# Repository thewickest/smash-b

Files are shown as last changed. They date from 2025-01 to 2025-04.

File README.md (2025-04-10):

# Smashboard
Ortholinear bluetooth split keyboard.

Just another split keyboard. Developed with KiKad7.0 and Fusion360.

ZMK configuration in [Smashboard-config](https://github.com/thewickest/smashboard-config)





# Features
- Powered by nice!nano microcontroller
- Compatible with nice!view OLED screen
- Hotswap for MX style Switches
- Different types of cases
- ZMK
- VIA Support
- Bluetooth

# Assembly
Parts needed. I will be linking the parts that I used. Feel free to use other parts, specially for the switches and the hotswap sockets. You can also change the remaining parts but you will have to modify the PCB most probably.
- 2x nice!nano
- 2x nice!view (optional)
- 44x MX Style switches
- 44x Hotswap sockets
- 48x Millmax sockets
- 10x millmax headers sockets
- 2x JST Battery connector (optional)
- 2x Power off/on switch
- 2x Reset button

# Roadmap
- [ ] Hotswap for low profile switches
- [x] Shell case

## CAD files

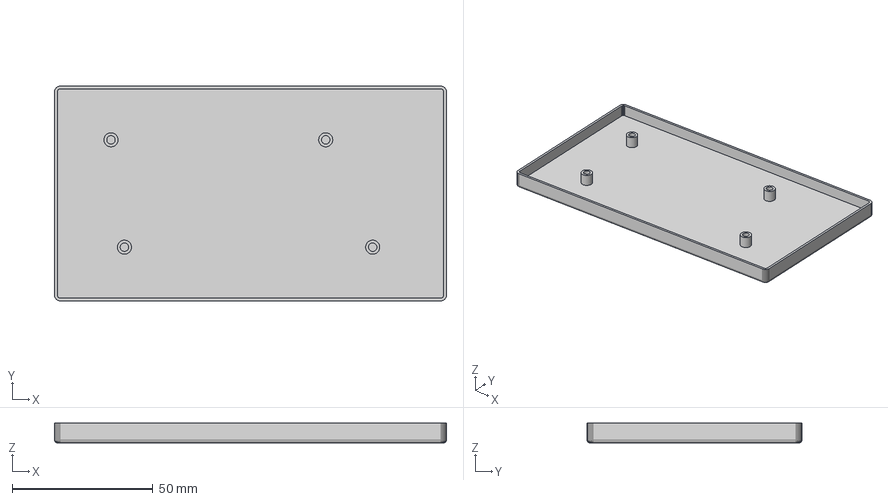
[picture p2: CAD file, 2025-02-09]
case/notoppings/notoppings.step
139.1 x 76.2 x 7.00 mm

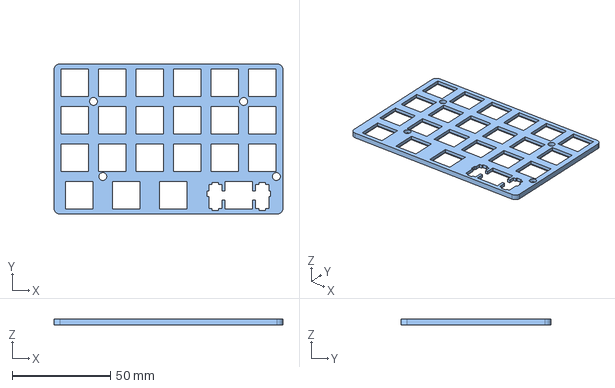
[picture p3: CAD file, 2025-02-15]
case/plate.step
116.3 x 76.2 x 3.00 mm

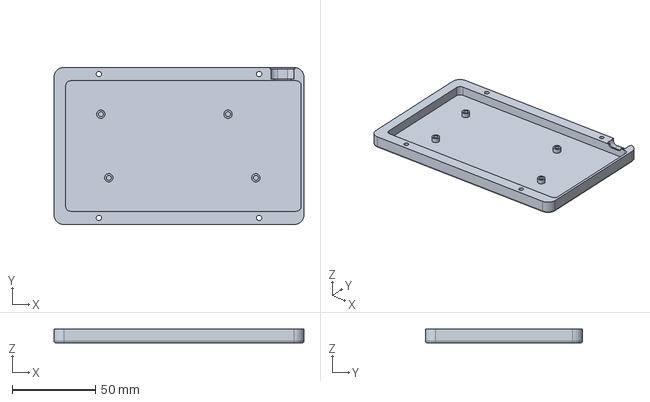
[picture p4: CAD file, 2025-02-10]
case/theclassic/theclassic-bottom.step
149.8 x 94.2 x 8.19 mm

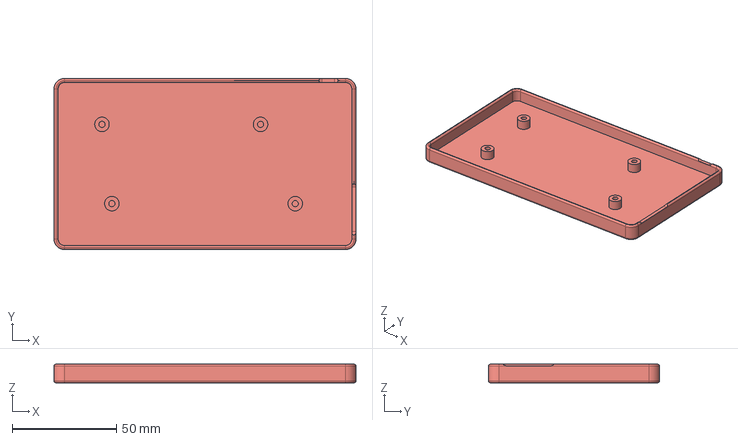
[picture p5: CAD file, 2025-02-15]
case/twopatties/twopatties.step
145.1 x 82.2 x 9.00 mm

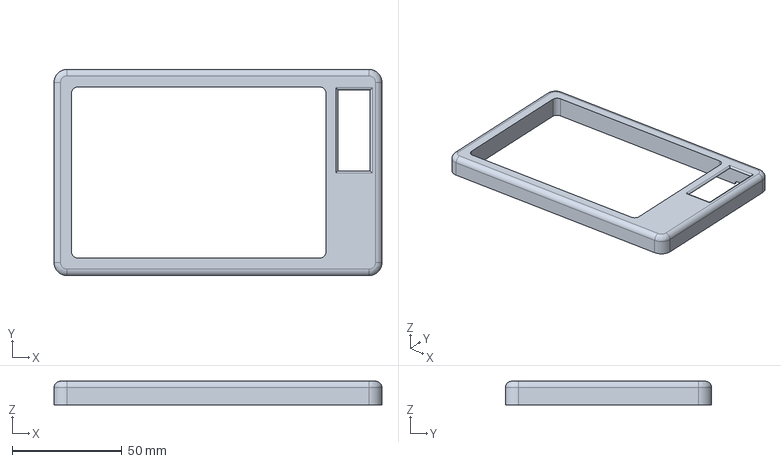
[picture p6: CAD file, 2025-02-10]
case/theclassic/theclassic-top.step
149.8 x 94.2 x 10.8 mm

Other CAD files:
case/notoppings/notoppings.obj
case/theclassic/theclassic-bottom.obj
case/theclassic/theclassic-top.obj

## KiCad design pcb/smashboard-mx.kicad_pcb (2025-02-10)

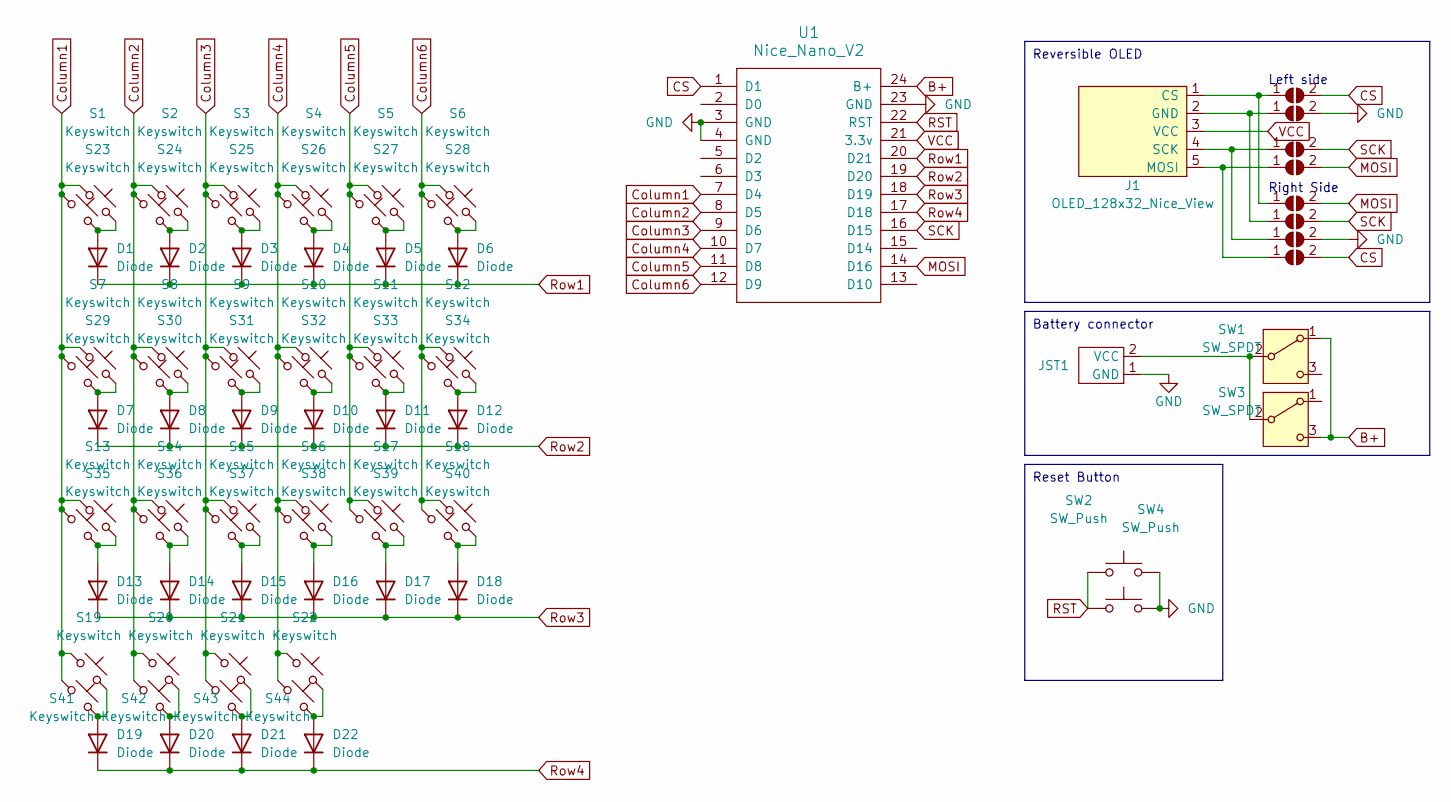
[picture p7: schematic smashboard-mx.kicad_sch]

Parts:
D1, D2, D3, D4, D5, D6, D7, D8, D9, D10, D11, D12, D13, D14, D15, D16, D17, D18, D19, D20, D21, D22: Diode; Diode_DO-35
J1: OLED_128x32_Nice_View
JP1, JP2, JP4, JP5, JP6, JP7, JP9, JP10: SolderJumper_2_Open; SolderJumper-2_P1.3mm_Open_TrianglePad1.0x1.5mm
JST1: JST_PH_S2B-PH-K_1x02_P2.00mm_Horizontal
S1, S2, S3, S4, S5, S6, S7, S8, S9, S10, S11, S12, S13, S14, S15, S16, S17, S18, S19, S20, S21, S22, S23, S24, S25, S26, S27, S28, S29, S30, S31, S32, S33, S34, S35, S36, S37, S38, S39, S40, S41, S42, S43, S44: Keyswitch; Hotswap_MX
SW1, SW3: SW_SPDT; SW_SPDT_PCM12
SW2, SW4: SW_Push; Panasonic_EVQPUK_EVQPUB
U1: Nice_Nano_V2

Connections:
B+: SW1.1 (A), SW3.3 (C), U1.24 (B+)
CS: JP1.2 (B), JP10.2 (B), U1.1 (D1)
Column1: S1.1, S7.1, S13.1, S19.1, S23.1, S29.1, S35.1, S41.1, U1.7 (D4)
Column2: S2.1, S8.1, S14.1, S20.1, S24.1, S30.1, S36.1, S42.1, U1.8 (D5)
Column3: S3.1, S9.1, S15.1, S21.1, S25.1, S31.1, S37.1, S43.1, U1.9 (D6)
Column4: S4.1, S10.1, S16.1, S22.1, S26.1, S32.1, S38.1, S44.1, U1.10 (D7)
Column5: S5.1, S11.1, S17.1, S27.1, S33.1, S39.1, U1.11 (D8)
Column6: S6.1, S12.1, S18.1, S28.1, S34.1, S40.1, U1.12 (D9)
GND: JP2.2 (B), JP9.2 (B), JST1.1 (GND), SW2.2, SW4.2, U1.3 (GND), U1.4 (GND), U1.23 (GND)
MOSI: JP5.2 (B), JP6.2 (B), U1.14 (D16)
unnamed: D1.2 (A), S1.2, S23.2
unnamed: D2.2 (A), S2.2, S24.2
unnamed: D3.2 (A), S3.2, S25.2
unnamed: D4.2 (A), S4.2, S26.2
unnamed: D5.2 (A), S5.2, S27.2
unnamed: D6.2 (A), S6.2, S28.2
unnamed: D7.2 (A), S7.2, S29.2
unnamed: D8.2 (A), S8.2, S30.2
unnamed: D9.2 (A), S9.2, S31.2
unnamed: D10.2 (A), S10.2, S32.2
unnamed: D11.2 (A), S11.2, S33.2
unnamed: D12.2 (A), S12.2, S34.2
unnamed: D13.2 (A), S13.2, S35.2
unnamed: D14.2 (A), S14.2, S36.2
unnamed: D15.2 (A), S15.2, S37.2
unnamed: D16.2 (A), S16.2, S38.2
unnamed: D17.2 (A), S17.2, S39.2
unnamed: D18.2 (A), S18.2, S40.2
unnamed: D19.2 (A), S19.2, S41.2
unnamed: D20.2 (A), S20.2, S42.2
unnamed: D21.2 (A), S21.2, S43.2
unnamed: D22.2 (A), S22.2, S44.2
unnamed: J1.1 (CS), JP1.1 (A), JP6.1 (A)
unnamed: J1.2 (GND), JP2.1 (A), JP7.1 (A)
unnamed: J1.5 (MOSI), JP5.1 (A), JP10.1 (A)
unnamed: J1.4 (SCK), JP4.1 (A), JP9.1 (A)
unnamed: JST1.2 (VCC), SW1.2 (B), SW3.2 (B)
RST: SW2.1, SW4.1, U1.22 (RST)
Row1: D1.1 (K), D2.1 (K), D3.1 (K), D4.1 (K), D5.1 (K), D6.1 (K), U1.20 (D21)
Row2: D7.1 (K), D8.1 (K), D9.1 (K), D10.1 (K), D11.1 (K), D12.1 (K), U1.19 (D20)
Row3: D13.1 (K), D14.1 (K), D15.1 (K), D16.1 (K), D17.1 (K), D18.1 (K), U1.18 (D19)
Row4: D19.1 (K), D20.1 (K), D21.1 (K), D22.1 (K), U1.17 (D18)
SCK: JP4.2 (B), JP7.2 (B), U1.16 (D15)
VCC: J1.3 (VCC), U1.21 (3.3v)

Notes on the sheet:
Reset Button
Reversible OLED
Battery connector
Left side
Right Side

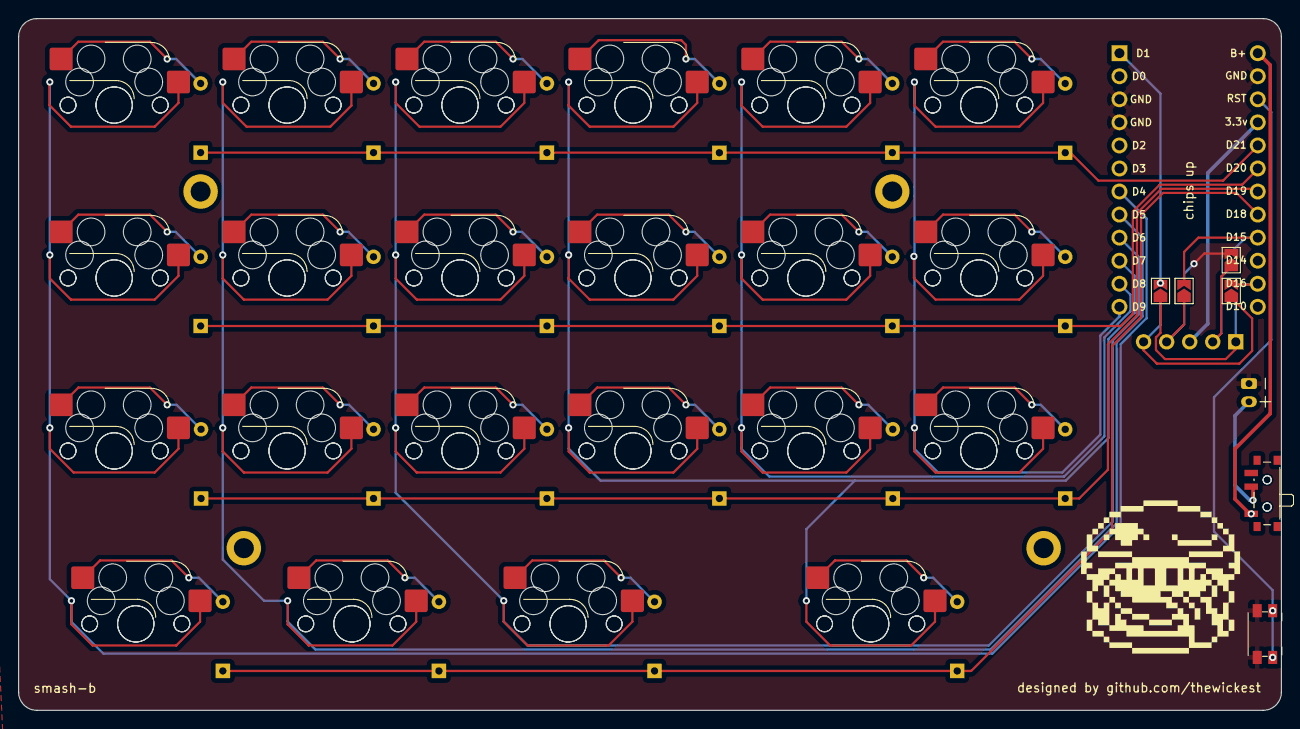
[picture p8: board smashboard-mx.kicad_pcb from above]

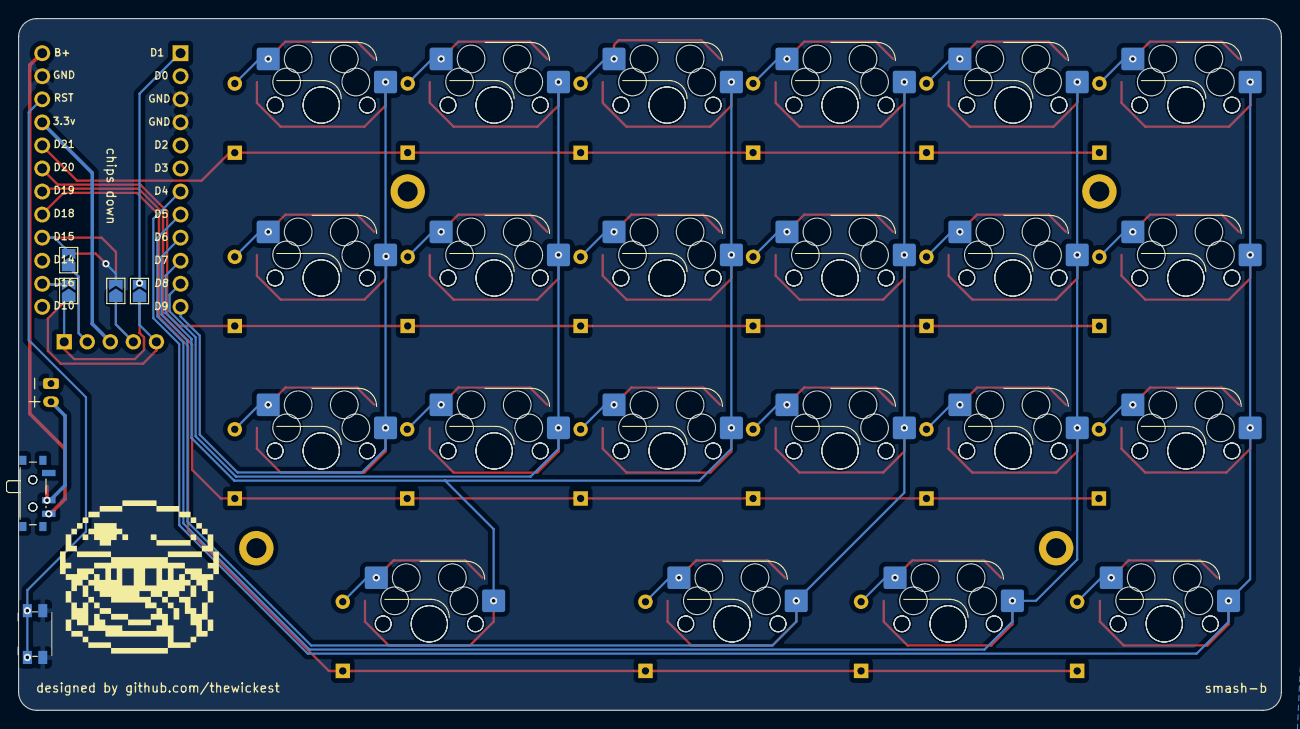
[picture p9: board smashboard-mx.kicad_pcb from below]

Board: 2 copper layers, 139.1 x 76.2 mm, 81 parts (50 on the bottom side), 44 nets.

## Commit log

2025-01-24 Initial Smash Board
    [bom.csv, designators.csv, positions.csv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]
2025-01-25 PCB: Reset button, on/off button and some modification in the vias
    [smashboard.kicad_pcb, smashboard.kicad_sch]
2025-01-25 Modified reset and on/off buttons footprints
    [smashboard.kicad_pcb, smashboard.kicad_sch]
2025-01-25 Some errors after changing the switch footprint
    [smashboard.kicad_pcb]
2025-01-29 PCB for MX and Kailh switches
    [smashboard-mx.kicad_pcb, smashboard-mx.kicad_sch]
2025-02-03 Add M2 holes into the PCB
    [smashboard-mx.kicad_pcb]
2025-02-03 Move reset button
    [smashboard-mx.kicad_pcb]
2025-02-04 Add Logo and name
    [smashboard-mx.kicad_pcb]
2025-02-04 Production files
    [bom.csv, designators.csv, positions.csv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]
2025-02-09 New Case - notoppings
    [notoppings.obj, notoppings.step]
2025-02-09 Reorder folders
    [bom.csv, designators.csv, positions.csv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]
2025-02-10 The Classic case
    [theclassic-bottom.obj, theclassic-bottom.step, theclassic-top.obj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]
2025-02-15 Two patties case
    [plate.step, twopatties.step]
2025-02-15 PCB image
